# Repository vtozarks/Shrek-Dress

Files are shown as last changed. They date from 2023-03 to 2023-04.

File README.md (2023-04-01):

This repo contains Arduino Nano code used for contol of LEDs used in the "wedding dress" used in the 2023 Lyric Theater Vermont prentation of Shrek.

## Pin Connections
### D2 
The D2 pin is configured as an input with internal pull-up and controls the operating mode of the LEDs

- Pull D2 low to initiate a ramp up from off to max brightness random sequence
- Continue to hold D2 low to to maintain random sequence at max brightness
- Allow D2 to pull-up to ramp dowm to off with random sequence

### D3-D12
D3 to D12 pins are outputs and used to drive the "DI" (data input) of 10 separate Neopixel 60 LED 1 meter strips (e.g. Adafruit product ID [2541](https://www.adafruit.com/product/2541)).  *While theoretically possible to drive multiple strips from a signle digital output, that was found to not be reliable so a single line to each strip was chosen.* 

## Operation
The Arduino code to control the LED strips utilized the "[FastLED](https://fastled.io/)" library for control of the LED strings.  Development utilized version 3.5.0 of the library. *Note that when using this library the use of Arduino interupts is very limited so they were not be used in this code given performance was adequate by just using a simple main loop.*

All 10 LED strings will be written with the same 60 value data array on each write/update operation.  When LEDs are active all strings will display the same random sequence of green values where brightness is varied between 0 (off) and a maximum brightness value.  While the FastLED library supports brightness values from 0 (off) to 0xFF (full on), the absolute max brightness is limited in this code to 0x80 (half full scale) to maximize run time on a battery while provided a resonable max brightness.  The absolute maximum brightness used by the code is controlled via the MAX_BRIGHTNESS defined constant.

It is assumed the D2 line will be controlled via a wireless realy switch with a "COM" (common), "NO" (normally open) and a "NC (normally closed) set of connections - a.k.a. a "Form-C" relay configuration.  The D2 pin is assumed to be connected to COM of the relay.  The relay "NC" connection should be left unconnected/open and the "NO" should be tied to ground.  The de-energized relay will leave the D2 line open and the internal pull up will pull the signal to HIGH.  When the relay is energized the D2 line will be connected to the "NO" ground connection and thus pulled LOW.  The D2 pin state will be checked in the main Arduino code loop to set the operating mode of the LED strips.  It is suggested (not required) to have the relay in its deenrgized state when the Arduino is powered up. ***NOTE: it is important that the ground reference of the controlling relay be connected to the ground reference of the Arduino to ensure correct operation.***

The following describes the basic states or operating modes of the LED strips:  The LED strips are considered in the "off" state if all LEDs are off (brightness value of 0).  The LED strips are considered "on" is all LEDs are on and displaying a random sequence of brightness values with the maximum brightness at the MAX_BRIGHTNESS value.

**LED strip currently "off" + D2 LOW: (off)**
- LED strips will reamin off

**LED strip currently "off" + D2 HIGH: (ramp up)**
- LED strips will display a random sequence with the brightness slowly ramping up in brightness to the MAX_BRIGHTNESS value

**LED strip currently "on" + D2 HIGH: (on)**
- LED strips will reamin on but contantly update with each LED having brightness values between o and MAX_BRIGHTNESS

**LED strip currently "on" + D2 LOW: (ramp down)**
- LED strips will display a random sequence with the brightness slowly ramping down in brightness to eventually be full off

*Note that the ramping up and ramping down sequences are "blocking" and changing the state of D2 during these sequences will have no impact on the current ramping operation.  Changes in D2 state are only acted on when the LED strips are in the "on" or "off" state.*

## Adjustmets ##
The behavior of the ramp up and ramp down sequences can be adjusted in code.  The LEDStripRampUpBrightness and LEDStripRampDownBrightness functions take arguements for the number of brightness steps in the sequence as well as a minimum time to spend at each brightness step.  The actual step sized is dependent on the MAX_BRIGHTNESS constant agiven both ramping sequences range from/to 0 (off) to/from that MAX_BRIGHTNESS value. The combination of the number of steps and the time per step determines the overall length of the ramping sequence.

## Other ##
When using a fully charged 2000 mAH battery and a MAX_BRIGHTNESS value of 0x80, a run time of greater than 90 minutes was observed which should provide more than ample head room for a single scene in the performance.

Two cases were 3D printed and STL files for them is available in the "Cases" folder within the repo.  The first case holds the Nano and a 5V 2000 mAH USB power bank.  The second holds the relay switch and a 11.1V battery.  These cases were designed around specific HW including....
- Standard Arduino Nano
- 5V 2000mAH lithium ion power bank (Harbor Freight "Armstrong" SKU 64977)
- 11.1V 2000mAH LiPo batter (cyclindrical - typical of Airsoft gun)
- Form-C 433MHz Wireless relay switch (eMyLo R121A)

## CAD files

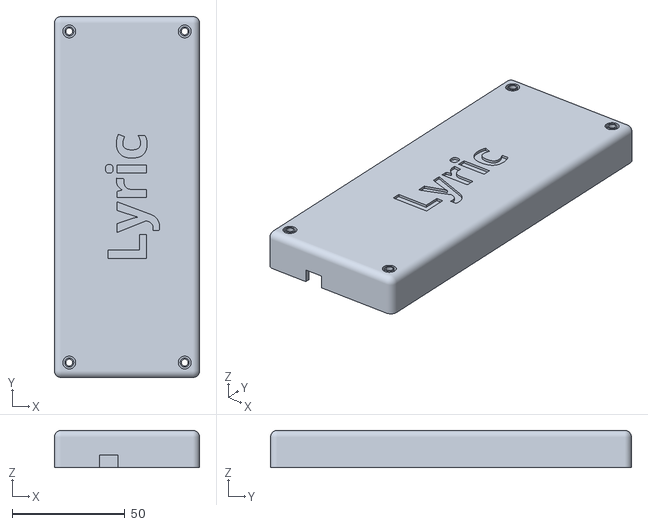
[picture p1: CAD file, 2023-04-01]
Cases/Shrek Nano Lid.stl
64.5 x 160.2 x 16.5

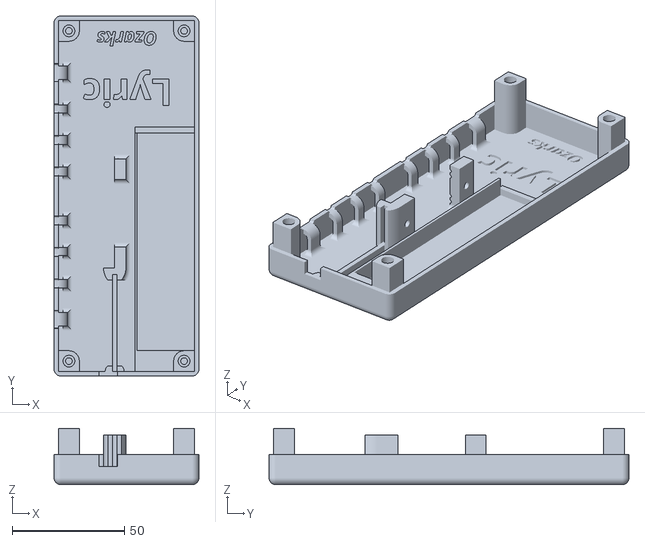
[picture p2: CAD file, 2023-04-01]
Cases/Shrek Nano Bottom.stl
64.5 x 160.2 x 25.0

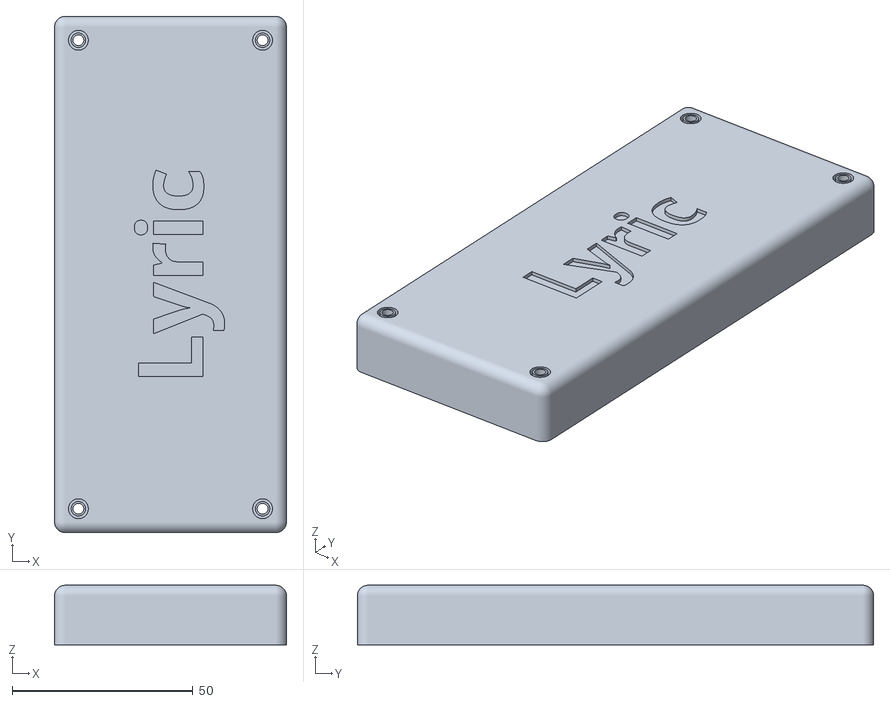
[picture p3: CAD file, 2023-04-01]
Cases/Shrek Relay Lid.stl
64.2 x 143.0 x 16.5

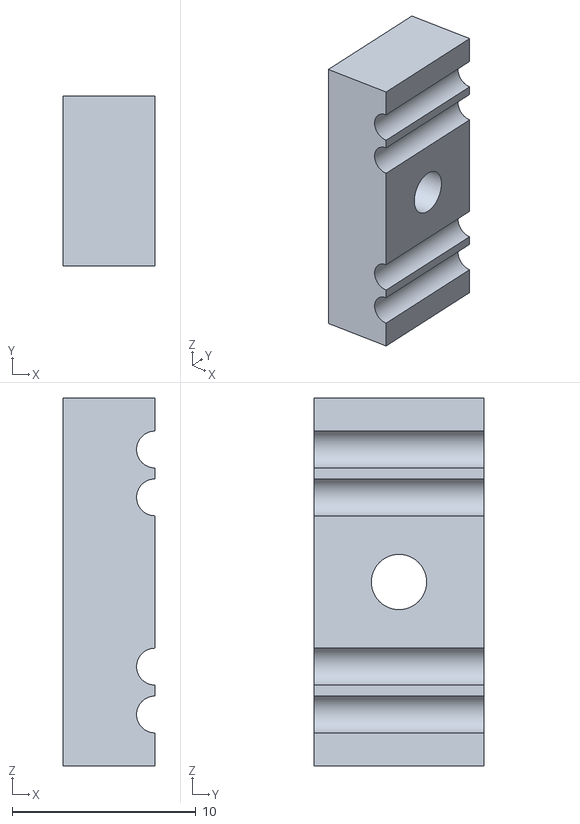
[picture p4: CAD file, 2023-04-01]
Cases/Shrek_Nano_Clamp.stl
5.00 x 9.25 x 20.0

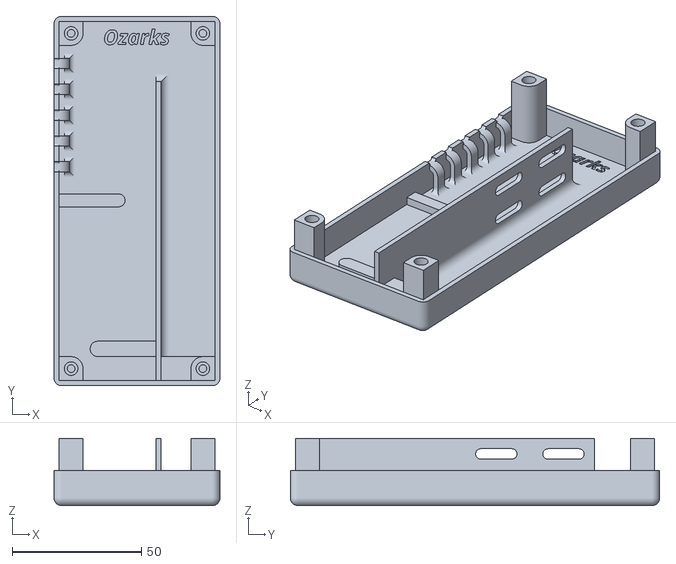
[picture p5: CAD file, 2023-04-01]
Cases/Shrek Relay Bottom.stl
64.2 x 143.0 x 26.0

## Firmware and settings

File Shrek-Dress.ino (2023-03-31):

//================================================================================
// Example NeoPixel code for Arduino Nano using FastLED library
// Library Manager: FastLED by Daniel Garcia V3.5.0 
//                  https://github.com/FastLED/FastLED
//================================================================================
#include <FastLED.h>

#define NUM_LEDS 60             //<- Number of LEDs on strip
#define DATA_PIN_1 4            //<- Arduino Nano pin for LED strip "Data In"
#define DATA_PIN_2 5            //<- Arduino Nano pin for LED strip "Data In"
#define DATA_PIN_3 6            //<- Arduino Nano pin for LED strip "Data In"
#define DATA_PIN_4 7            //<- Arduino Nano pin for LED strip "Data In"
#define DATA_PIN_5 8            //<- Arduino Nano pin for LED strip "Data In"
#define DATA_PIN_6 9            //<- Arduino Nano pin for LED strip "Data In"
#define DATA_PIN_7 10           //<- Arduino Nano pin for LED strip "Data In"
#define DATA_PIN_8 11           //<- Arduino Nano pin for LED strip "Data In"
#define DATA_PIN_9 3           //<- Arduino Nano pin for LED strip "Data In"
#define DATA_PIN_10 12           //<- Arduino Nano pin for LED strip "Data In"
#define SWITCH_PIN  2           //<- Arduino Nano pin for switch state (INT0)
#define MIN_BRIGHTNESS 0
#define MAX_BRIGHTNESS 0x80

enum LEDMode {LED_OFF, LED_RAMP_UP, LED_RAMP_DOWN, LED_SEQUENCE};

CRGB leds[NUM_LEDS];            //<- FastLED required array for LEDs
int CurrentBrightness = 0;      //<- The current Brightness level
LEDMode CurrentLEDMode = LED_OFF;

//___ Function protoypes __________________________________________________________
void LEDStripSequence(int brightness);
void LEDStripRampUpBrightness(int steps, unsigned long msPerStep, int startBrightness, int stopBrightness);
void LEDStripRampDownBrightness(int steps, unsigned long msPerStep, int startBrightness, int stopBrightness);
void LEDRingSequence(int brightness);
void LEDRingRampBrightness(int steps, unsigned long msPerStep, int startBrightness, int stopBrightness);

//=================================================================================
// Setup before main loop
//   - assume AdaFruit NeoPixel (WS2812 / GRB ordering )
//=================================================================================
void setup() 
{ 
  //___ Init serial monitor for debug _____________________________________________
  //Serial.begin(9600);
  //Serial.println("*I* Executing Setup");

  //___ Init random number generator _______________________________________________
  randomSeed(analogRead(0));
  
  //___ Init LEDs off ______________________________________________________________
  FastLED.addLeds<NEOPIXEL, DATA_PIN_1>(leds, NUM_LEDS);  
  FastLED.addLeds<NEOPIXEL, DATA_PIN_2>(leds, NUM_LEDS);  
  FastLED.addLeds<NEOPIXEL, DATA_PIN_3>(leds, NUM_LEDS);  
  FastLED.addLeds<NEOPIXEL, DATA_PIN_4>(leds, NUM_LEDS);  
  FastLED.addLeds<NEOPIXEL, DATA_PIN_5>(leds, NUM_LEDS);  
  FastLED.addLeds<NEOPIXEL, DATA_PIN_6>(leds, NUM_LEDS);  
  FastLED.addLeds<NEOPIXEL, DATA_PIN_7>(leds, NUM_LEDS);  
  FastLED.addLeds<NEOPIXEL, DATA_PIN_8>(leds, NUM_LEDS);  
  FastLED.addLeds<NEOPIXEL, DATA_PIN_9>(leds, NUM_LEDS);  
  FastLED.addLeds<NEOPIXEL, DATA_PIN_10>(leds, NUM_LEDS);  
  for (int idx = 0; idx < NUM_LEDS; idx++)
  {
      CHSV(HUE_GREEN, 255, 0x0);  
  }
  FastLED.show();

  //___Setup switch and init LED mode ______________________________________________
  pinMode(SWITCH_PIN, INPUT_PULLUP);  
  CurrentLEDMode == LED_OFF;
}

//=================================================================================
// Main loop 
//   - Repeat the LED sequence at the current brightness value
//=================================================================================
void loop() 
{ 

  LEDSetMode();
    
  if (CurrentLEDMode == LED_SEQUENCE)
  {
    LEDStripSequence(CurrentBrightness);  
    CurrentBrightness = MAX_BRIGHTNESS;     
  }
  else if (CurrentLEDMode == LED_RAMP_UP)
  {
    Serial.println("*I* Ramping Up");    
    LEDStripRampUpBrightness(16, 300, MIN_BRIGHTNESS, MAX_BRIGHTNESS);  
    CurrentBrightness = MAX_BRIGHTNESS;     
    CurrentLEDMode = LED_SEQUENCE;    
  }
  else if (CurrentLEDMode == LED_RAMP_DOWN)
  {
    Serial.println("*I* Ramping Down");    
    LEDStripRampDownBrightness(16, 300, MAX_BRIGHTNESS, MIN_BRIGHTNESS); 
    CurrentBrightness = MIN_BRIGHTNESS; 
    CurrentLEDMode = LED_OFF;    
  }
  else if (CurrentLEDMode == LED_OFF)
  {
        
  }
 
}

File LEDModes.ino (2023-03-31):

//=================================================================================
// Determine the state of the pin and set the LED operating mode
//=================================================================================
void LEDSetMode()
{
  //___ Get current switch state __________________________________________________  
  int switchState = digitalRead(SWITCH_PIN);
  
  if ((switchState == HIGH) && (CurrentLEDMode == LED_SEQUENCE))
  {
    CurrentLEDMode = LED_RAMP_DOWN;
  }
  else if ((switchState == LOW) && (CurrentLEDMode != LED_SEQUENCE))
  {
    CurrentLEDMode = LED_RAMP_UP;
  }
  
}

//=================================================================================
// Operating sequence for LED Strip (random brightness variation of green)
//=================================================================================
void LEDStripSequence(int brightness)
{
  int targetLED = random(0, 30);
  int rndBrightness = random(MIN_BRIGHTNESS, brightness);

  leds[targetLED] = CHSV(HUE_GREEN, 255, rndBrightness);
  leds[targetLED+30] = CHSV(HUE_GREEN, 255, rndBrightness);
  FastLED.show();
    
}

//=====================================================================================
// Ramp up the brigthness of the LED strip sequence over the specified number of timed steps
//=====================================================================================
void LEDStripRampUpBrightness(int steps, 
                              unsigned long msPerStep, 
                              int startBrightness, 
                              int stopBrightness)
{
  //___ Brightness ________________________________________________________________
  bool done = false;
  int brightnessStep = (stopBrightness - startBrightness) / steps;
  int brightness = startBrightness;
     
  for (int stepIdx = 0; stepIdx <= steps; stepIdx++)
  {
    unsigned long startTime = millis();
    done = false;
    
    //___ Run the sequence for at least the specified time ________________________
    while (done == false)
    {
      //___ Execute a sequence ____________________________________________________          
      LEDStripSequence(brightness);
      if (millis()-startTime >= msPerStep)
      {
        done = true;        
      }      
    }
    //___ Adjust brightness for next step _________________________________________
    brightness = brightness + brightnessStep; 

    //___ Error check the brightness (must be 0 to 0xFF) __________________________
    if (brightness < 0)
    {           
      brightness = 0;
    }
    if (brightness > 0xFF)
    {           
      brightness = 0xFF;
    }

  }
}

//=====================================================================================
// Ramp up the brigthness of the LED strip sequence over the specified number of timed steps
//=====================================================================================
void LEDStripRampDownBrightness(int steps, 
                                unsigned long msPerStep, 
                                int startBrightness, 
                                int stopBrightness)
{
  //___ Brightness ________________________________________________________________
  bool done = false;
  int brightnessStep = (stopBrightness - startBrightness) / steps;
  int brightness = startBrightness;


  for (int stepIdx = 0; stepIdx <= steps; stepIdx++)
  {
    unsigned long startTime = millis();
    done = false;

    //___ Init the LED to random with new max brightness ____________________________
    for (int idx = 0; idx < NUM_LEDS; idx++)
    {
      int rndBrightness = random(MIN_BRIGHTNESS-5, brightness); 
      if (rndBrightness < 0)
      {
        rndBrightness = 0;              
      }                               
      leds[idx] = CHSV(HUE_GREEN, 255, rndBrightness);                                    
    }                        

    //___ Run the sequence for at least the specified time ________________________
    while (done == false)
    {
      //___ If ramping down limit the current values to new max ___________________         
      if (brightnessStep < 0)
      {
      }
      //___ Execute a sequence ____________________________________________________          
      LEDStripSequence(brightness);
      if (millis()-startTime >= msPerStep)
      {
        done = true;        
      }      
    }
    //___ Adjust brightness for next step _________________________________________
    brightness = brightness + brightnessStep; 

    //___ Error check the brightness (must be 0 to 0xFF) __________________________
    if (brightness < 0)
    {           
      brightness = 0;
    }
    if (brightness > 0xFF)
    {           
      brightness = 0xFF;
    }

  }
}

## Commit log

2023-03-31 Removed LED ring code
2023-04-01 Added STL files and updated readme
    [Shrek Nano Bottom.stl, Shrek Nano Lid.stl, Shrek Relay Bottom.stl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]
